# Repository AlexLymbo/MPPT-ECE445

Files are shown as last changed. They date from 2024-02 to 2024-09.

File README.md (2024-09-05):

# Senior Design Project(ECE445) - Custom Illini Solar Car MPPT
This project contains both the HW and FW for a boost converter MPPT made for the 3rd generation vehicle of Illini Solar Car. It utilizes a simple perturb and observe algorithm (P&O).

## More Info: 
The goal of this project was to develop custom and low cost solar Maximum Power Point Trackers (MPPTs). These MPPTs use a boost converter to optimize power output from the solar array to charge the battery efficiently. With the array divided into three sections for reliability, each MPPT gives redundancy to the system. Customization gives simple integration with the vehicle's electrical systems, allowing for plug-and-play functionality. This cost-effective solution takes away the need for expensive off-the-shelf components and provides access to schematics for easy maintenance and upgrades. 

https://www.youtube.com/watch?v=uG63rXX1FN4&t=2s

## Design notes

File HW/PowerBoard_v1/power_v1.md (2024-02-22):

# Wheel v8.1
**Board Requirements**

## Overview and Description
- This board is the steering wheel on the car including most of the I/O from/to the driver. 
- This replaces Wheel v7 as it is a new mechanical design and adds more input functionality.
- Most of the functionality will be combined into one PCB:
	- The wheel bridge board has the major power protection circuitry on it.
- Other board integration
	- Dash (CAN)
	- MCC (CAN)
	- BMS (CAN)
	- PDS (CAN)
	- PTT Radio (Hard wire)
- Wiki page: [Wheel v8](https://wiki.illinisolarcar.com/w/index.php/Wheel_v8)

## High-Level Requirements
- Microcontroller
	- [LPC1549](https://www.nxp.com/docs/en/data-sheet/LPC15XX.pdf)
	- Integrated CAN
	- JTAG Programming
	- Reset buttons
- Driver Controls
	- Turn Signals
		- A three position switch for right, left, and no turn options
	- Push To Talk
		- Comply with ASC/WSC hands free rules
		- Work independently of car
	- Horn
	- Accelerator
		- Analog input, at least 120 values within movement range of encoder
	- Regen
		- Analog input, at least 120 values within movement range of encoder
	- Cruise mode enable
	- Coast button
	- Reset
	- OK/Flag Button
		- To allow driver to flag abnormalities and menu interaction
	- Directional button
		- For menu interaction
- Informational Displays
	- OLED 
		- Powered and controlled by the steering wheel, also mounted to steering wheel
		- Provides real-time telemetry data to driver from all CANBUS-connected PCBs
		- Driver can customize what telemetry is visible on the screen
		- Driver must control from steering wheel
	- 7 Segment Displays
		- Display speed independent of what the driver is doing on the menu
- LED Indicators
	- Indicate status of turn signal/hazard lights, parking lights, and head lights / DRLs
		- Must comply with pilot light size requirements
- External Connections
	- Can only use 12, all via quick disconnect hub
- Mechanical Design
	- Except for the display, everything should be on one PCB or panel mounted to the wheel itself. 
	- All components will be on one side except those with cutouts to the front and items ?mm(unknown at this point) in height in other areas
	- Care must be taken not to interfere with usage of the disconnect hub	

## Communication Protocols
- CAN Bus
	- Used to receive all needed data and send driver commands
	- Termination will be available on the steering wheel
	- CAN Planes will be isolated from main wheel power planes
- SPI
	- Used with encoder, 7-seg, and OLED

## Connectors
- 12 Pin Quick Disconnect hub
    - 5 Wire CAN
	- 1 Wire +24V Critical
	- 1 Wire GND Critical
	- 1 Wire Connection Sense
	- 2 PTT Wires
	- 2 Free (any cool ideas?)
- Low profile connectors should be used to prevent the anything from getting knocked loose in normal use
- Using microclasp connectors

## ICs
- X,Y axis accelerometer to detect wheel turning

## Buttons/Switches
- Buttons are described in high level requirements
- Non-SMD or THT buttons will have connectors next to them
- All buttons will go to GPIO pins
- Buttons should be panel mount
- Menu button should be a 1-axis toggle

## Power System
- +24V
	- Input power from LV Bus
	- Must be 24V through wheel connector due to wire ratings/limits
	- Power protection will occur on the wheel bridge
- +3.3V
	- DC-DC converter on the wheel will provide 24V -> 3.3V
	     - Alternatively 3.3V may be powered via USB for re-programming
	- Used to power everything on the board and all peripherals
- USB Power
    - +5V via micro-usb, regulated to 3.3V as secondary 3.3V supply
- CAN Power
    - Input from 5-Wire CAN Connections
	- Fused On Board
	- Should be ~+12V
- +5V CAN
    - Regulated from CAN Power
	- Power Isolated CAN Side of CAN Transciever

## Test Points
- +24V
- +SuperCap Power
- +3.3V
- I2C SCL & SDA
- SPI CLK/MOSI/MISO1/MISO2/Chip Selects
- Connection Sense
- SuperCap Power Sense
- GND where needed as Reference
- CAN +/- & H/L

## LED Indicators
- Onboard LEDs:
	- Heartbeat
	- CAN Receive
	- CAN Send
	- Displays functionality
	- CAN Termination

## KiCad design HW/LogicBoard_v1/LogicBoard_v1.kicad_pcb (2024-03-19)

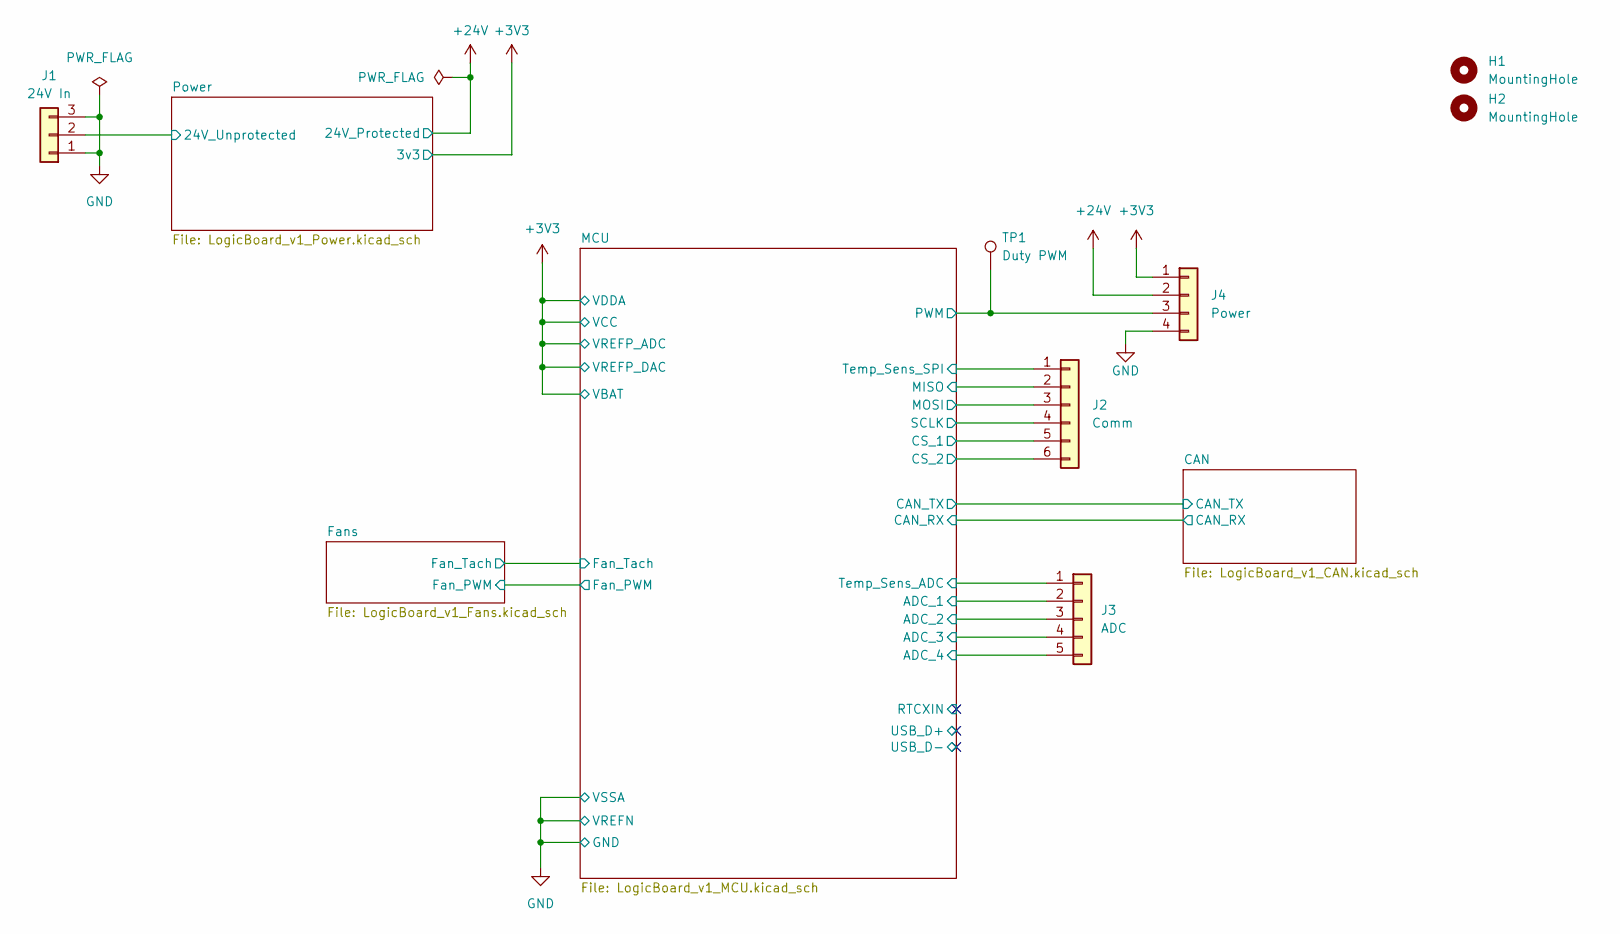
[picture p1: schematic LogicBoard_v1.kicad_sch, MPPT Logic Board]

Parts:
H1, H2: MountingHole; MountingHole_3.2mm_M3
J1: 24V In; Molex_Micro-Fit_3.0_43650-0300_1x03_P3.00mm_Horizontal; MPN 436500300
J2: Comm; Molex_Micro-Fit_3.0_43650-0600_1x06_P3.00mm_Horizontal; MPN 436500600
J3: ADC; Molex_Micro-Fit_3.0_43650-0500_1x05_P3.00mm_Horizontal; MPN 436500500
J4: Power; Molex_Micro-Fit_3.0_43650-0400_1x04_P3.00mm_Horizontal; MPN 436500400
TP1: Duty PWM; TestPoint_THTPad_D1.5mm_Drill0.7mm

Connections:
+3V3: J4.1; also elsewhere on the board
+24V: J4.2; also elsewhere on the board
/MCU/ADC_1: J3.2; also elsewhere on the board
/MCU/ADC_2: J3.3; also elsewhere on the board
/MCU/ADC_3: J3.4; also elsewhere on the board
/MCU/ADC_4: J3.5; also elsewhere on the board
/MCU/CS_1: J2.5; also elsewhere on the board
/MCU/CS_2: J2.6; also elsewhere on the board
/MCU/MISO: J2.2; also elsewhere on the board
/MCU/MOSI: J2.3; also elsewhere on the board
/MCU/PWM: J4.3, TP1.1; also elsewhere on the board
/MCU/SCLK: J2.4; also elsewhere on the board
/MCU/Temp_Sens_ADC: J2.1, J3.1; also elsewhere on the board
/Power/24V_Unprotected: J1.2; also elsewhere on the board
GND: J1.1, J1.3, J4.4; also elsewhere on the board

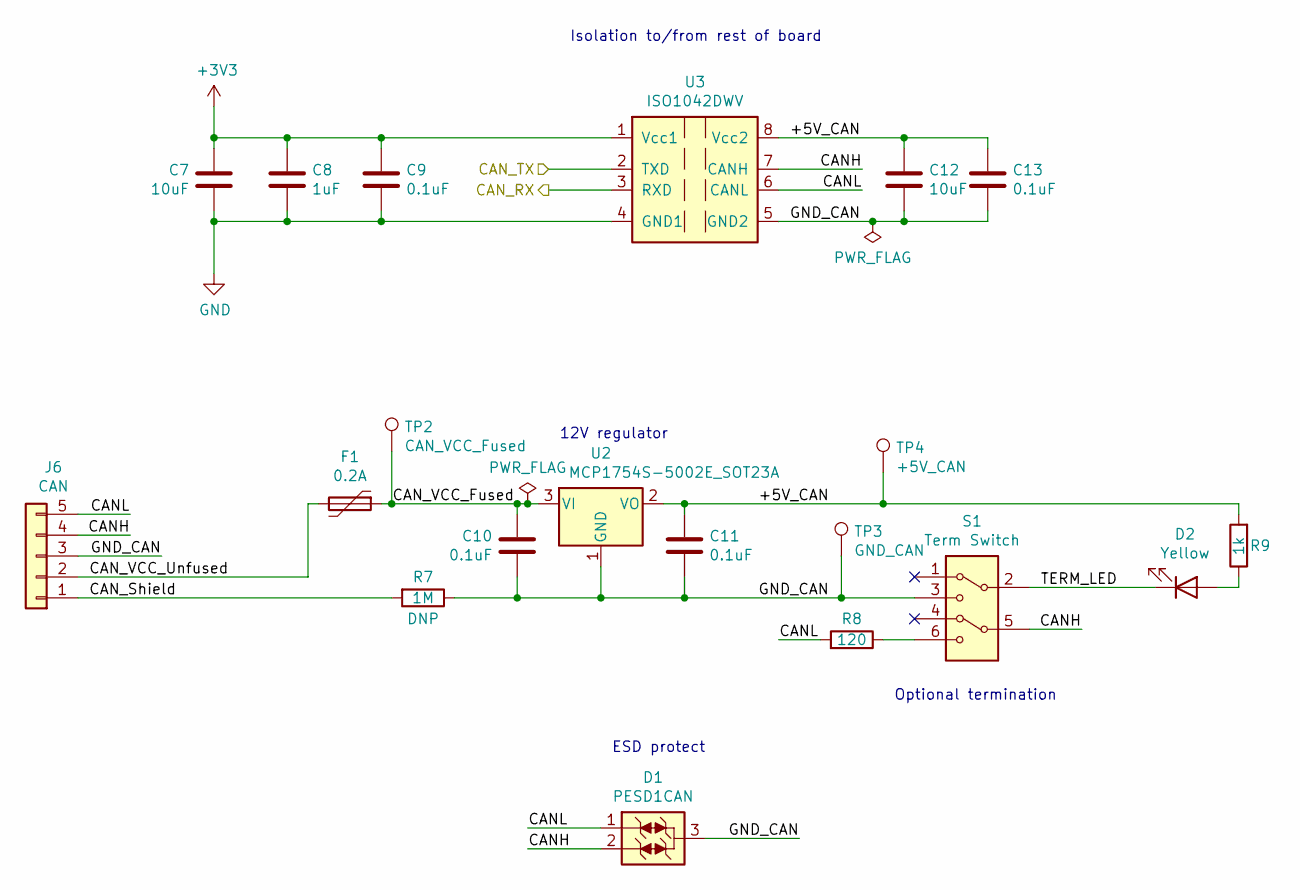
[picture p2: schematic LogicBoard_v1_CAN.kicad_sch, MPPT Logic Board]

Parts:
C7: 10uF; C_1206_3216Metric_Pad1.33x1.80mm_HandSolder; MPN CAP CER 10UF 10V X5R 1206
C8: 1uF; C_0805_2012Metric_Pad1.18x1.45mm_HandSolder; MPN CAP CER 1UF 10V X5R 0805
C9, C11: 0.1uF; C_0603_1608Metric_Pad1.08x0.95mm_HandSolder; MPN CAP CER 0.1UF 10V X5R 0603
C10: 0.1uF; C_0603_1608Metric_Pad1.08x0.95mm_HandSolder; MPN CAP CER 0.1UF 16V X5R 0603
C12: 10uF; C_1206_3216Metric_Pad1.33x1.80mm_HandSolder; MPN CAP CER 10UF 25V X5R 1206
C13: 0.1uF; C_0603_1608Metric_Pad1.08x0.95mm_HandSolder; MPN CAP CER 0.1UF 25V X5R 0603
D1: PESD1CAN; SOT-23; MPN PESD1CAN,215
D2: Yellow; LED_0603_1608Metric_Pad1.05x0.95mm_HandSolder; MPN LED YELLOW CLEAR 0603 SMD
F1: 0.2A; Fuse_1206_3216Metric_Pad1.42x1.75mm_HandSolder; MPN PTC RESET FUSE 30V 200MA 1206
J6: CAN; M12_5-pin_90deg_VertPitch2.54mm; MPN 1694224
R7: 1M; R_0603_1608Metric_Pad0.98x0.95mm_HandSolder; MPN RES SMD 1M OHM 1% 1/10W 0603
R8: 120; R_1206_3216Metric_Pad1.30x1.75mm_HandSolder; MPN RES SMD 120 OHM 1% 1/4W 1206
R9: 1k; R_0603_1608Metric_Pad0.98x0.95mm_HandSolder; MPN RES SMD 1K OHM 5% 1/10W 0603
S1: CL-SB-22B-01; DPDT_NIDEC_6_pin_SMD_1.6_x_1.2_pads; MPN CL-SB-22B-01
TP2: CAN_VCC_Fused; TestPoint_THTPad_D1.5mm_Drill0.7mm
TP3: GND_CAN; TestPoint_THTPad_D1.5mm_Drill0.7mm
TP4: +5V_CAN; TestPoint_THTPad_D1.5mm_Drill0.7mm
U2: MCP1754S-5002E_SOT23A; SOT-23; MPN MCP1754S-5002E_SOT23A
U3: ISO1042DWV; SOIC-8_5.85x7.4mm_P1.27mm; MPN ISO1042DWV

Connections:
+3V3: C7.1, C8.1, C9.1, U3.1 (Vcc1); also elsewhere on the board
/CAN/+5V_CAN: C11.1, C12.1, C13.1, R9.2, TP4.1, U2.2 (VO), U3.8 (Vcc2)
/CAN/CANH: D1.2 (K), J6.4, S1.5, U3.7 (CANH)
/CAN/CANL: D1.1 (K), J6.5, R8.2, U3.6 (CANL)
/CAN/CAN_RX: U3.3 (RXD); also elsewhere on the board
/CAN/CAN_Shield: J6.1, R7.2
/CAN/CAN_TX: U3.2 (TXD); also elsewhere on the board
/CAN/CAN_VCC_Fused: C10.1, F1.1, TP2.1, U2.3 (VI)
/CAN/CAN_VCC_Unfused: F1.2, J6.2
/CAN/GND_CAN: C10.2, C11.2, C12.2, C13.2, D1.3 (A), J6.3, R7.1, S1.3, TP3.1, U2.1 (GND), U3.5 (GND2)
/CAN/TERM_LED: D2.1 (K), S1.2
GND: C7.2, C8.2, C9.2, U3.4 (GND1); also elsewhere on the board
unnamed: D2.2 (A), R9.1
unnamed: R8.1, S1.6

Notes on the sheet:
ESD protect
12V regulator
Optional termination
Isolation to/from rest of board

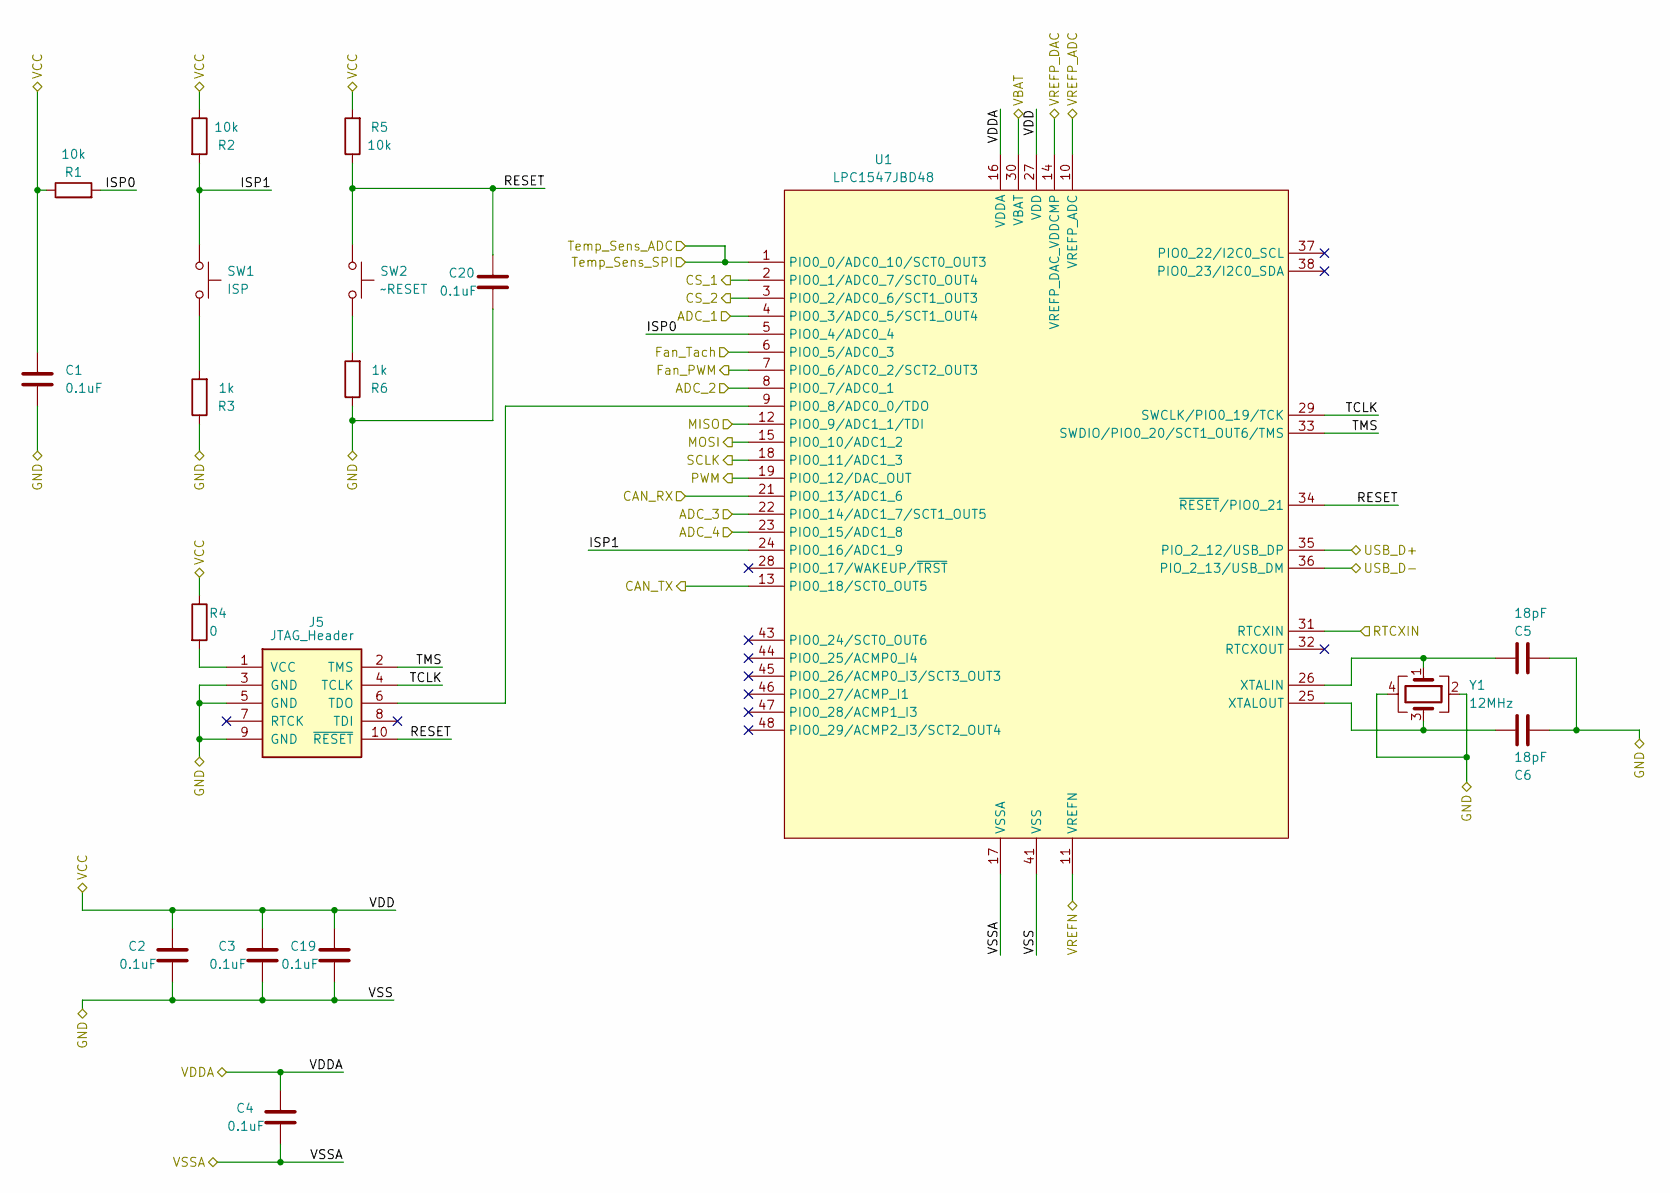
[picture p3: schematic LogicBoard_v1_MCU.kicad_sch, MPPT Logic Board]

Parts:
C1, C2, C3, C4, C19, C20: 0.1uF; C_0603_1608Metric_Pad1.08x0.95mm_HandSolder; MPN CAP CER 0.1uF 10V X7R 0603
C5, C6: 18pF; C_0603_1608Metric_Pad1.08x0.95mm_HandSolder; MPN CAP CER 18pF 10V X7R 0603
J5: JTAG_Header; IDC-Header_2x05_Pitch1.27mm_Straight; MPN 3220-10-0100-00
R1, R2, R5: 10k; R_0603_1608Metric_Pad0.98x0.95mm_HandSolder; MPN RES SMD 10K OHM 1% 1/4W 0603
R3, R6: 1k; R_0603_1608Metric_Pad0.98x0.95mm_HandSolder; MPN RES SMD 1K OHM 5% 1/4W 0603
R4: 0; R_0603_1608Metric_Pad0.98x0.95mm_HandSolder; MPN RES SMD 0 OHM 5% 1/4W 0603
SW1: ISP; Button_223AM; MPN 223AMVAAR
SW2: ~RESET; Button_223AM; MPN 223AMVAAR
U1: LPC1547JBD48; LQFP-48_7x7mm_P0.5mm; MPN LPC1547JBD48
Y1: 12MHz; Crystal_SMD_TXC_7M-4pin_3.2x2.5mm; MPN 7V-12.000MAAE-T

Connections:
+3V3: C1.1, C2.1, C3.1, C4.1, C19.1, R1.1, R2.1, R4.1, R5.2, U1.10 (VREFP_ADC), U1.14 (VREFP_DAC_VDDCMP), U1.16 (VDDA), U1.27 (VDD), U1.30 (VBAT), U1.39 (VDD), U1.42 (VDD); also elsewhere on the board
/CAN/CAN_RX: U1.21 (PIO0_13/ADC1_6); also elsewhere on the board
/CAN/CAN_TX: U1.13 (PIO0_18/SCT0_OUT5); also elsewhere on the board
/Fans/Fan_PWM: U1.7 (PIO0_6/ADC0_2/SCT2_OUT3); also elsewhere on the board
/Fans/Fan_Tach: U1.6 (PIO0_5/ADC0_3); also elsewhere on the board
/MCU/ADC_1: U1.4 (PIO0_3/ADC0_5/SCT1_OUT4); also elsewhere on the board
/MCU/ADC_2: U1.8 (PIO0_7/ADC0_1); also elsewhere on the board
/MCU/ADC_3: U1.22 (PIO0_14/ADC1_7/SCT1_OUT5); also elsewhere on the board
/MCU/ADC_4: U1.23 (PIO0_15/ADC1_8); also elsewhere on the board
/MCU/CS_1: U1.2 (PIO0_1/ADC0_7/SCT0_OUT4); also elsewhere on the board
/MCU/CS_2: U1.3 (PIO0_2/ADC0_6/SCT1_OUT3); also elsewhere on the board
/MCU/ISP0: R1.2, U1.5 (PIO0_4/ADC0_4)
/MCU/ISP1: R2.2, SW1.1, U1.24 (PIO0_16/ADC1_9)
/MCU/MISO: U1.12 (PIO0_9/ADC1_1/TDI); also elsewhere on the board
/MCU/MOSI: U1.15 (PIO0_10/ADC1_2); also elsewhere on the board
/MCU/PWM: U1.19 (PIO0_12/DAC_OUT); also elsewhere on the board
/MCU/RESET: C20.1, J5.10 (~RESET), R5.1, SW2.1, U1.34 (~RESET/PIO0_21)
/MCU/RTCXIN: U1.31 (RTCXIN)
/MCU/SCLK: U1.18 (PIO0_11/ADC1_3); also elsewhere on the board
/MCU/TCLK: J5.4 (TCLK), U1.29 (SWCLK/PIO0_19/TCK)
/MCU/TMS: J5.2 (TMS), U1.33 (SWDIO/PIO0_20/SCT1_OUT6/TMS)
/MCU/Temp_Sens_ADC: U1.1 (PIO0_0/ADC0_10/SCT0_OUT3); also elsewhere on the board
/MCU/USB_D+: U1.35 (PIO_2_12/USB_DP)
/MCU/USB_D-: U1.36 (PIO_2_13/USB_DM)
GND: C1.2, C2.2, C3.2, C4.2, C5.1, C6.1, C19.2, C20.2, J5.3 (GND), J5.5 (GND), J5.9 (GND), R3.1, R6.1, U1.11 (VREFN), U1.17 (VSSA), U1.20 (VSS), U1.40 (VSS), U1.41 (VSS), Y1.2, Y1.4; also elsewhere on the board
unnamed: J5.6 (TDO), U1.9 (PIO0_8/ADC0_0/TDO)
unnamed: J5.1 (VCC), R4.2
unnamed: R3.2, SW1.2
unnamed: R6.2, SW2.2
unnamed: C5.2, U1.26 (XTALIN), Y1.1
unnamed: C6.2, U1.25 (XTALOUT), Y1.3

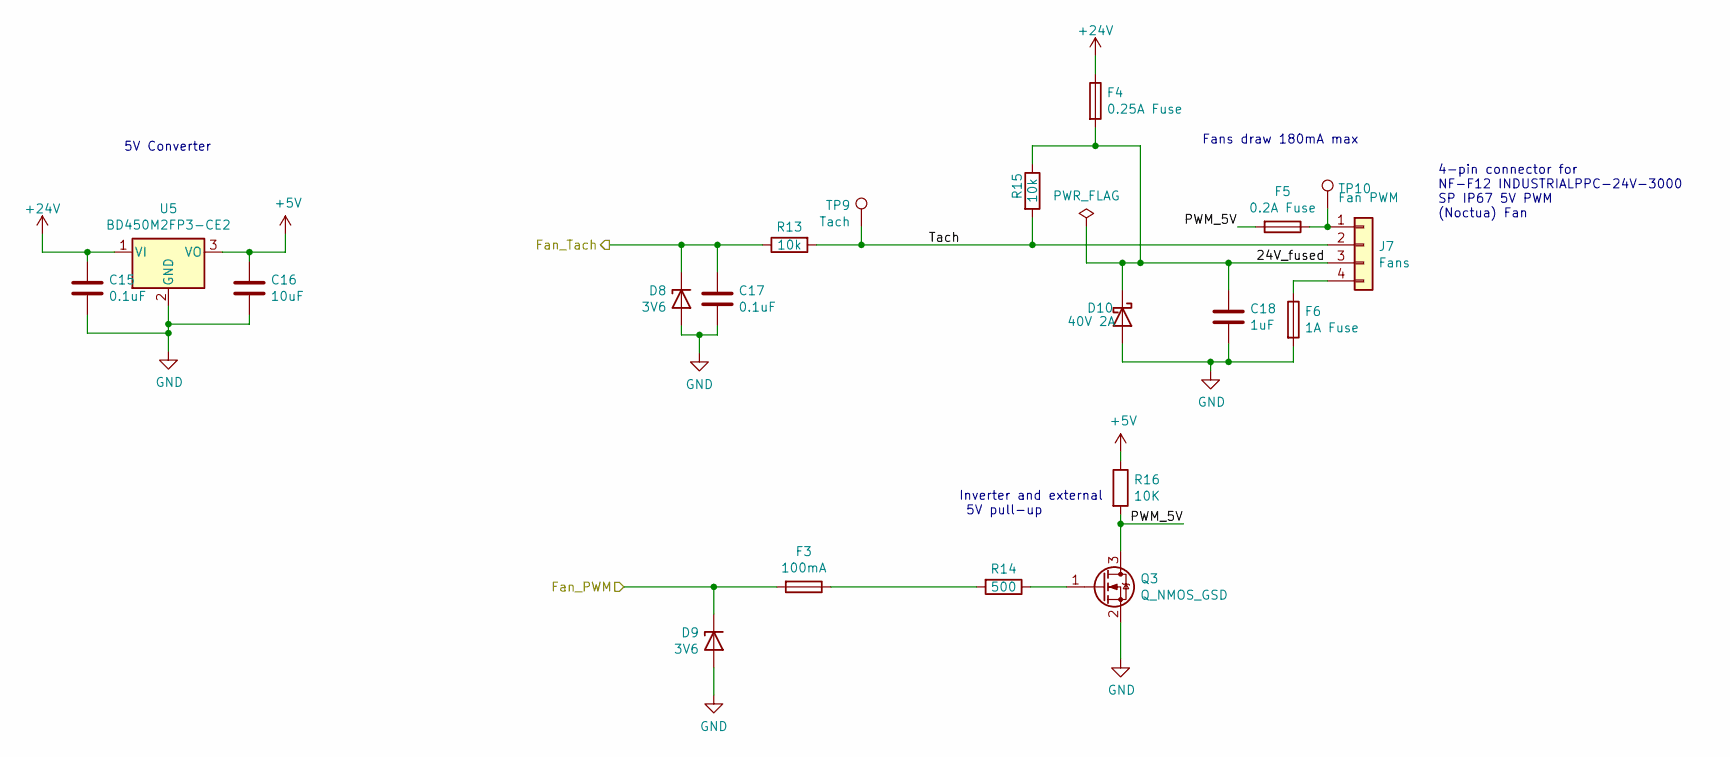
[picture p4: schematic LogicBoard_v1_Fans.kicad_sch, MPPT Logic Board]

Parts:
C15: 0.1uF; C_0603_1608Metric_Pad1.08x0.95mm_HandSolder; MPN CAP CER 0.1uF 50V X5R 0603
C16: 10uF; C_0603_1608Metric_Pad1.08x0.95mm_HandSolder; MPN CAP CER 10uF 10V X5R 0603
C17: 0.1uF; C_0603_1608Metric_Pad1.08x0.95mm_HandSolder; MPN CAP CER 0.1UF 10V X5R 0603
C18: 1uF; C_0603_1608Metric_Pad1.08x0.95mm_HandSolder; MPN CAP CER 1UF 50V X5R 0603
D8, D9: 3V6; D_SOD-123F; MPN NZH3V6B
D10: 40V 2A; D_1206_3216Metric_Pad1.42x1.75mm_HandSolder; MPN SD1206T040S2R0
F3: 100mA; Fuse_2512_6332Metric; MPN 0451.100MRL
F4: 0.25A Fuse; Fuse_1206_3216Metric_Pad1.42x1.75mm_HandSolder; MPN FUSE BOARD MNT 0.25A 32VDC 1206
F5: 0.2A Fuse; Fuse_1206_3216Metric_Pad1.42x1.75mm_HandSolder; MPN FUSE BOARD MNT 0.2A 32VDC 1206
F6: 1A Fuse; Fuse_1206_3216Metric_Pad1.42x1.75mm_HandSolder; MPN FUSE BOARD MNT 1A 32VDC 1206
J7: Fans; Molex_KK-254_AE-6410-04A_1x04_P2.54mm_Vertical
Q3: Q_NMOS_GSD; SOT-23_Handsoldering; MPN BSS123L
R13, R15: 10k; R_0603_1608Metric_Pad0.98x0.95mm_HandSolder; MPN RES SMD 10K OHM 5% 1/10W 0603
R14: 500; R_0603_1608Metric_Pad0.98x0.95mm_HandSolder; MPN RES SMD 500 OHM 5% 1/10W 0603
R16: 10K; R_0603_1608Metric_Pad0.98x0.95mm_HandSolder; MPN RES SMD 10k OHM 5% 1/10W 0603
TP9: Tach; TestPoint_THTPad_D1.5mm_Drill0.7mm
TP10: Fan PWM; TestPoint_THTPad_D1.5mm_Drill0.7mm
U5: BD450M2FP3-CE2; SOT-223-3_TabPin2; MPN BD450M2FP3-CE2

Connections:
+5V: C16.1, R16.1, U5.3 (VO)
+24V: C15.1, F4.1, U5.1 (VI); also elsewhere on the board
/Fans/24V_fused: C18.1, D10.1 (K), F4.2, J7.3, R15.1
/Fans/Fan_PWM: D9.1 (K), F3.2; also elsewhere on the board
/Fans/Fan_Tach: C17.2, D8.1 (K), R13.1; also elsewhere on the board
/Fans/PWM_5V: F5.2, Q3.3 (D), R16.2
/Fans/Tach: J7.2, R13.2, R15.2, TP9.1
GND: C15.2, C16.2, C17.1, C18.2, D8.2 (A), D9.2 (A), D10.2 (A), F6.2, Q3.2 (S), U5.2 (GND); also elsewhere on the board
unnamed: F3.1, R14.2
unnamed: F5.1, J7.1, TP10.1
unnamed: F6.1, J7.4
unnamed: Q3.1 (G), R14.1

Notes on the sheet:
5V Converter
4-pin connector for NF-F12 INDUSTRIALPPC-24V-3000 SP IP67 5V PWM (Noctua) Fan
Inverter and external 5V pull-up
Fans draw 180mA max

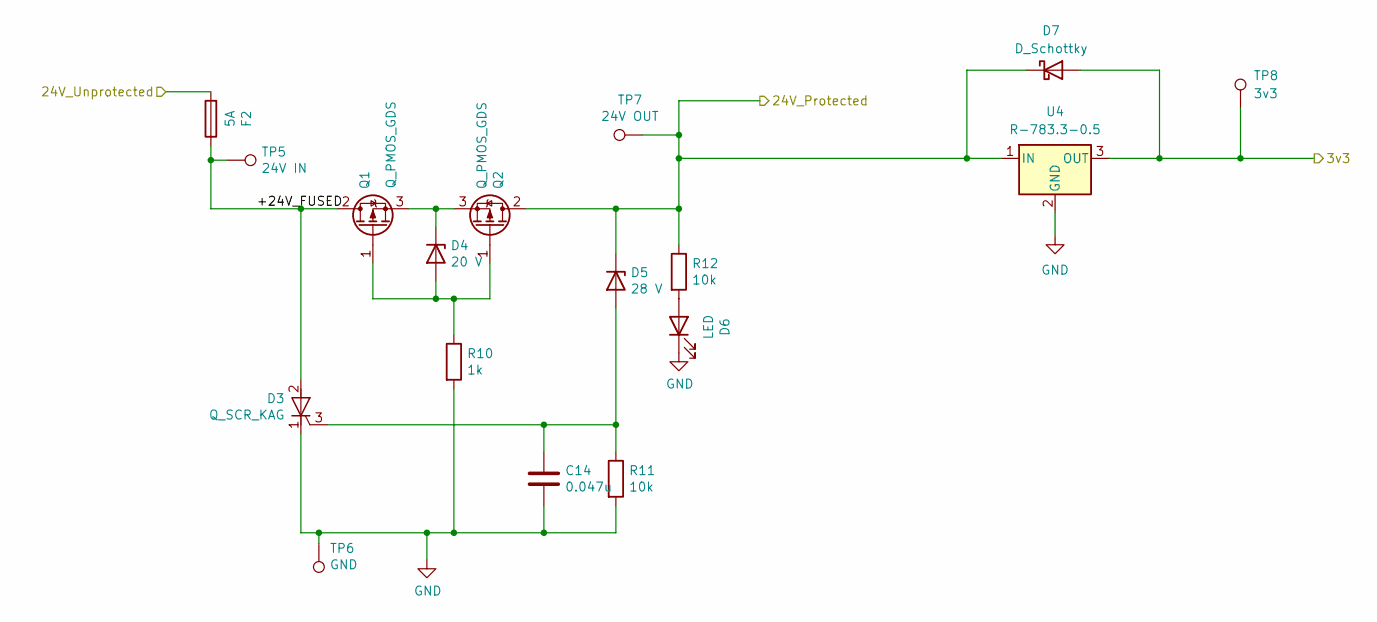
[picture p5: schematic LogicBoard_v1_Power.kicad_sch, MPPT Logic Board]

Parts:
C14: 0.047u; C_0603_1608Metric_Pad1.08x0.95mm_HandSolder; MPN CAP CER 0.047UF 50V X7R 0603
D3: Q_SCR_KAG; SOT-223-3_TabPin2; MPN S602TSRP
D4: 20 V; D_SOD-123F; MPN DIODE ZENER 20V 500MW SOD123F
D5: 28 V; D_SOD-123F; MPN DIODE ZENER 28V 500mW SOD123F
D6: LED; LED_0603_1608Metric_Pad1.05x0.95mm_HandSolder; MPN LED BLUE CLEAR 0603 SMD
D7: D_Schottky; D_SOD-123F; MPN BAT54H
F2: 5A; Littelfuse_154_4.24mm_x_3.81mm; MPN FUSE BOARD MNT 5A 125VAC/VDC SMD
Q1, Q2: Q_PMOS_GDS; TO-252-2; MPN FQD11P06
R10: 1k; R_0603_1608Metric_Pad0.98x0.95mm_HandSolder; MPN RES SMD 1K OHM 5% 0.1W 0603
R11, R12: 10k; R_0603_1608Metric_Pad0.98x0.95mm_HandSolder; MPN RES SMD 10K OHM 5% 0.1W 0603
TP5: 24V IN; TestPoint_THTPad_D1.5mm_Drill0.7mm
TP6: GND; TestPoint_THTPad_D1.5mm_Drill0.7mm
TP7: 24V OUT; TestPoint_THTPad_D1.5mm_Drill0.7mm
TP8: 3v3; TestPoint_THTPad_D1.5mm_Drill0.7mm
U4: R-783.3-0.5; Converter_DCDC_RECOM_R-78E-0.5_THT; MPN R-783.3-0.5

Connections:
+3V3: D7.2 (A), TP8.1, U4.3 (OUT); also elsewhere on the board
+24V: D5.1 (K), D7.1 (K), Q2.2 (D), R12.1, TP7.1, U4.1 (IN); also elsewhere on the board
/Power/24V_Unprotected: F2.2; also elsewhere on the board
/Power/+24V_FUSED: D3.2 (A), F2.1, Q1.2 (D), TP5.1
GND: C14.2, D3.1 (K), D6.1 (K), R10.2, R11.2, TP6.1, U4.2 (GND); also elsewhere on the board
unnamed: C14.1, D3.3 (G), D5.2 (A), R11.1
unnamed: D4.2 (A), Q1.1 (G), Q2.1 (G), R10.1
unnamed: D4.1 (K), Q1.3 (S), Q2.3 (S)
unnamed: D6.2 (A), R12.2

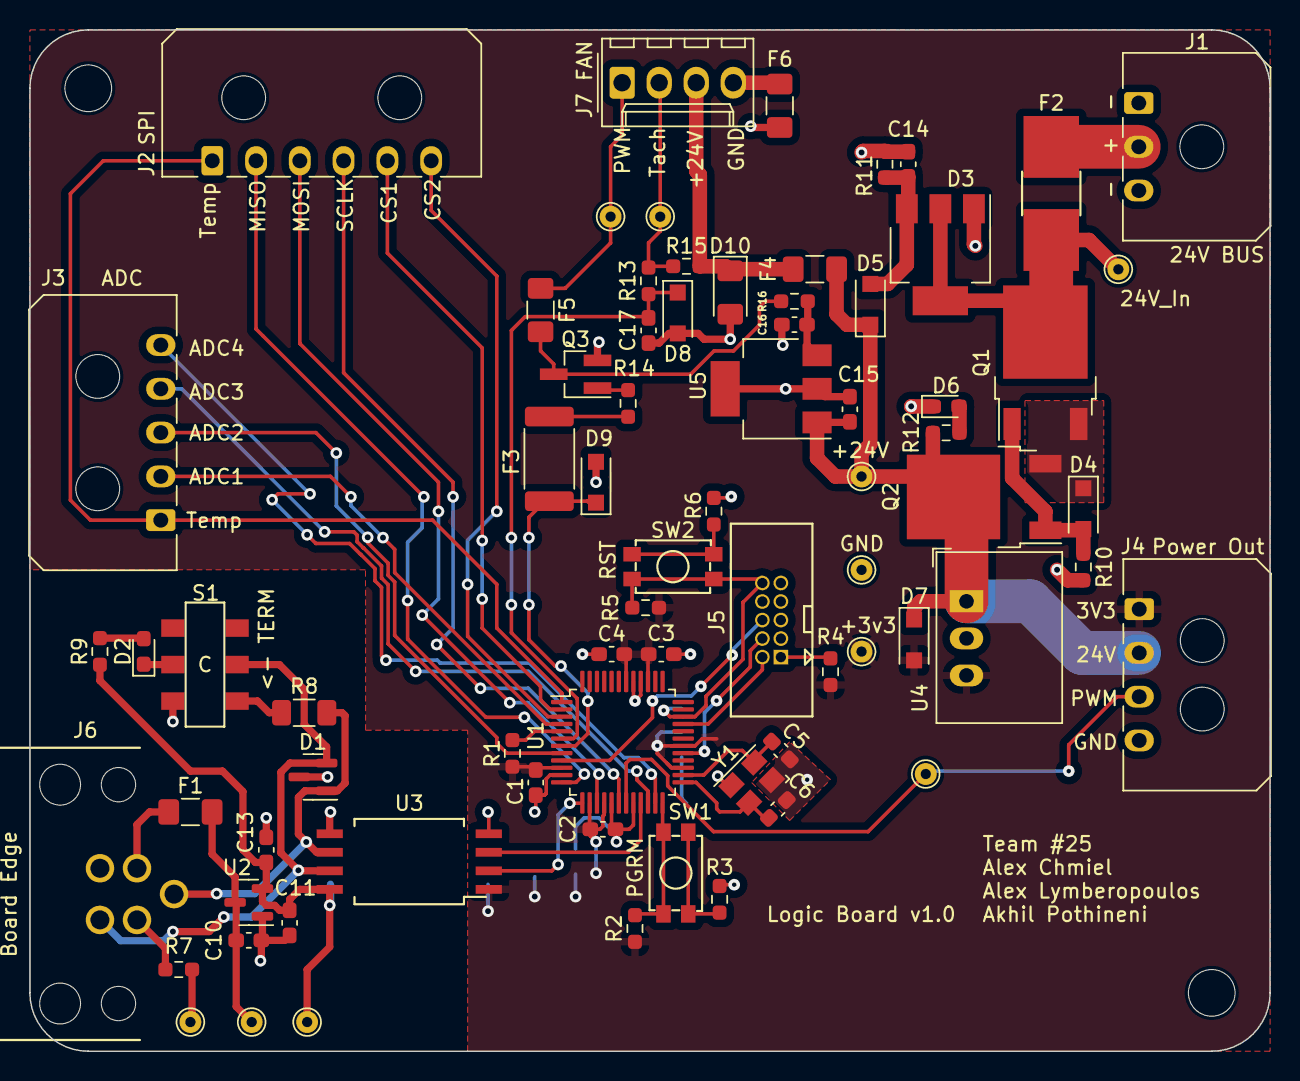
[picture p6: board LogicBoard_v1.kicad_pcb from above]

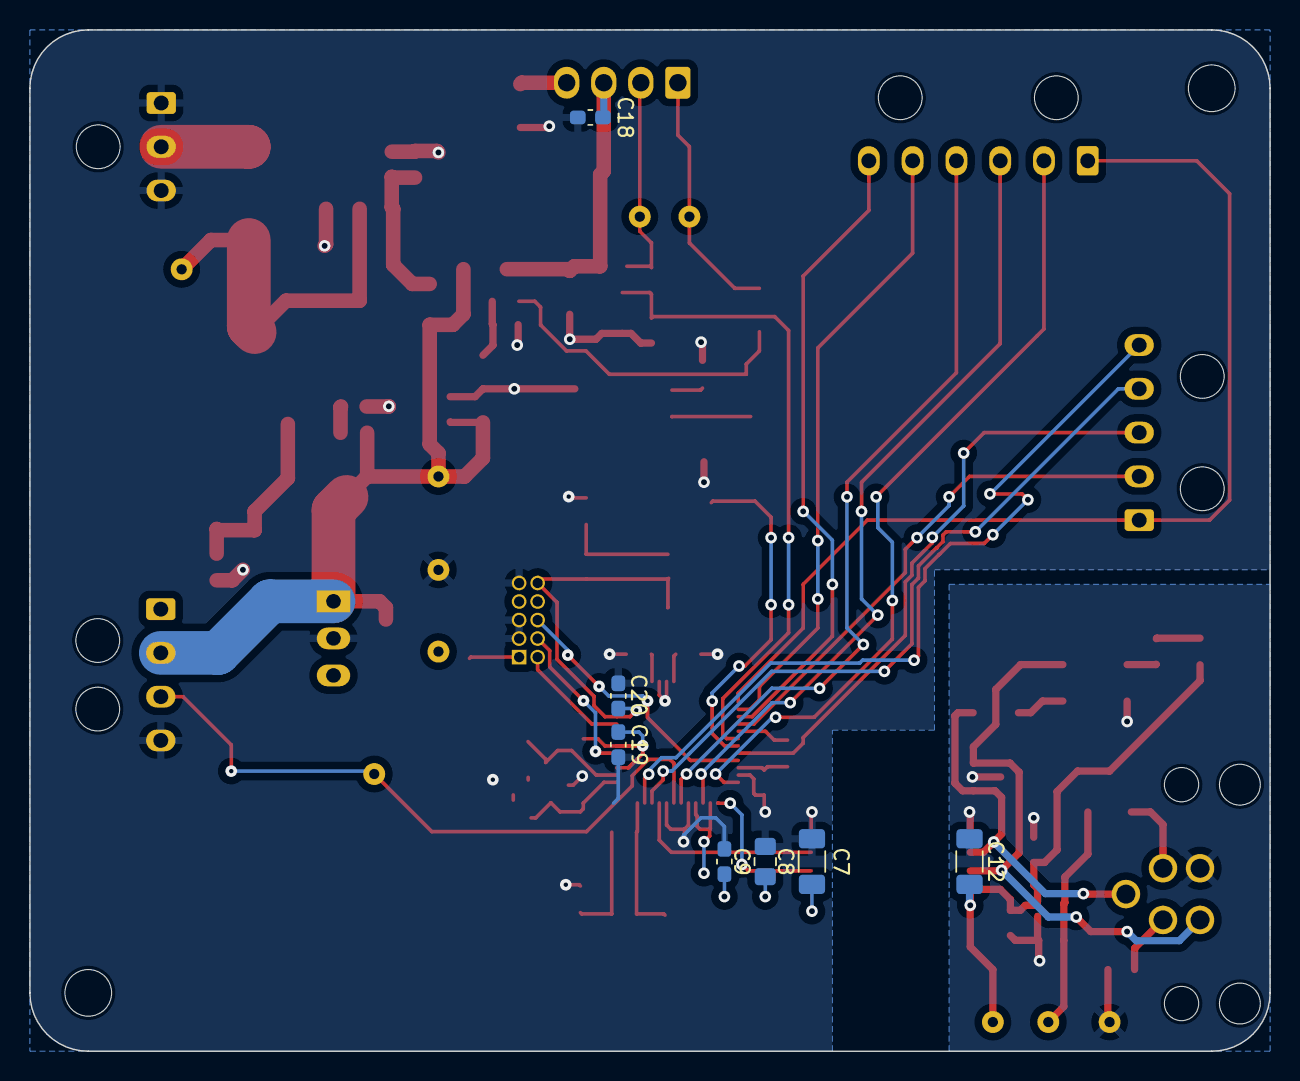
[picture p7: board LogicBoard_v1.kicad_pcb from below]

Board: 2 copper layers, 85.0 x 70.0 mm, 83 parts (7 on the bottom side), 53 nets.

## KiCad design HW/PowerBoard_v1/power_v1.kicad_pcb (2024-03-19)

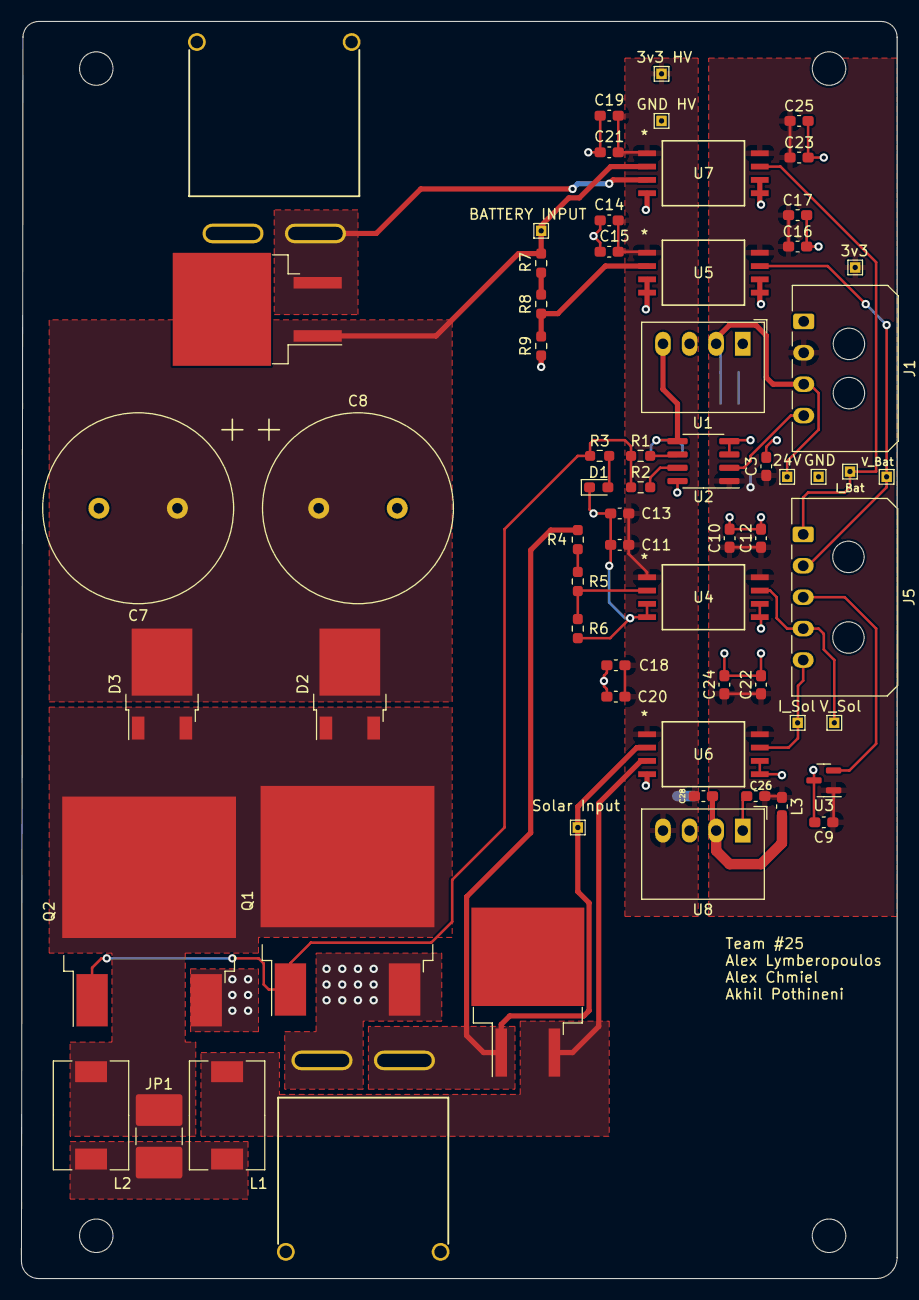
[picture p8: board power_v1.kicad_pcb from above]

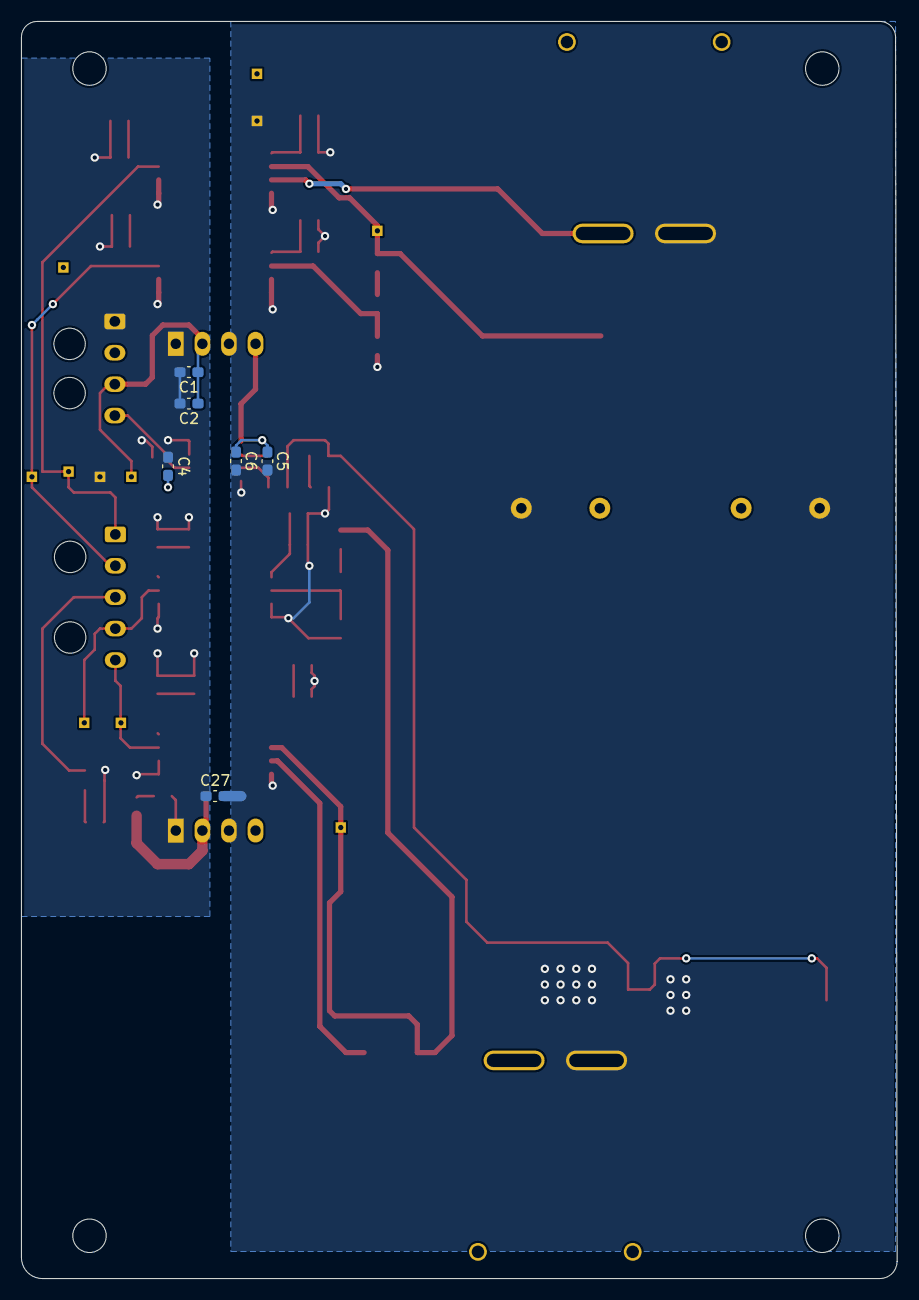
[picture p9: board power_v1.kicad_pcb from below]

Board: 2 copper layers, 83.6 x 120.1 mm, 75 parts (6 on the bottom side), 27 nets.

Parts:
C1, C26: 10uF; C_0603_1608Metric_Pad1.08x0.95mm_HandSolder
C2, C28: 1nF; C_0603_1608Metric_Pad1.08x0.95mm_HandSolder
C3, C4, C5, C6, C12, C13, C14, C17, C18, C19, C24, C25: 1uF; C_0603_1608Metric_Pad1.08x0.95mm_HandSolder
C7, C8: 470uF; C_Radial_D18.0mm_H35.5mm_P7.50mm
C9: 0.1uF; C_0603_1608Metric_Pad1.08x0.95mm_HandSolder
C10, C11, C15, C16, C20, C21, C22, C23: 100nF; C_0603_1608Metric_Pad1.08x0.95mm_HandSolder
C27: 2.2nF; C_0603_1608Metric_Pad1.08x0.95mm_HandSolder
D1: Blue; LED_0603_1608Metric_Pad1.05x0.95mm_HandSolder
D2, D3: 0.83V; TO-252-2
H1, H2, H3, H4: MountingHole; MountingHole_3.2mm_M3
J1: Inputs; Molex_Micro-Fit_3.0_43650-0400_1x04_P3.00mm_Horizontal
J3: Vin Solar; Anderson_Powerpole_45A_1x2_Horizontal_Bottom
J4: Vout Battery; Anderson_Powerpole_45A_1x2_Horizontal_Bottom
J5: Sensors; Molex_Micro-Fit_3.0_43650-0500_1x05_P3.00mm_Horizontal
JP1: SolderJumper_2_Open; R_2816_7142Metric
L1, L2: 1.2 μH; L_Wuerth_HCM-1050
L3: 22uH; L_0603_1608Metric_Pad1.05x0.95mm_HandSolder
Q1, Q2: IXTT220N20X4HV; TO-268-2
R1: 10; R_0603_1608Metric_Pad0.98x0.95mm_HandSolder
R2: 0; R_0603_1608Metric_Pad0.98x0.95mm_HandSolder
R3: 10k; R_0603_1608Metric_Pad0.98x0.95mm_HandSolder
R4, R5, R7, R8: 500k; R_0603_1608Metric_Pad0.98x0.95mm_HandSolder
R6: 53k; R_0603_1608Metric_Pad0.98x0.95mm_HandSolder
R9: 41.7k; R_0603_1608Metric_Pad0.98x0.95mm_HandSolder
R10, R11: 0.75; TO-263-2_isolatedback
TP1: +3V3A; TestPoint_THTPad_1.0x1.0mm_Drill0.5mm
TP2: GNDA; TestPoint_THTPad_1.0x1.0mm_Drill0.5mm
TP3: 24V; TestPoint_THTPad_1.0x1.0mm_Drill0.5mm
TP4: GND; TestPoint_THTPad_1.0x1.0mm_Drill0.5mm
TP5: 3V3; TestPoint_THTPad_1.0x1.0mm_Drill0.5mm
TP6: ADC V Sol; TestPoint_THTPad_1.0x1.0mm_Drill0.5mm
TP7, TP11: ADC V Batt; TestPoint_THTPad_1.0x1.0mm_Drill0.5mm
TP8: ADC I Sol; TestPoint_THTPad_1.0x1.0mm_Drill0.5mm
TP9, TP13: ADC I Batt; TestPoint_THTPad_1.0x1.0mm_Drill0.5mm
U1: RO-2412S; Converter_DCDC_RECOM_R-78S-0.1_THT
U2: STGAP2SMTR; SOIC-8_3.9x4.9mm_P1.27mm
U3: MCP9700AT-ETT; SOT-23
U4, U5, U6, U7: PAMC1350DWVR; U_PAMC1350DWVR_TEX
U8: 3v3 ISO DC/DC; Converter_DCDC_RECOM_R-78S-0.1_THT

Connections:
+3.3VA: C11.1, C13.1, C14.1, C15.1, C18.1, C19.1, C20.1, C21.1, C28.1, TP1.1, U4.1 (VDD1), U5.1 (VDD1), U6.1 (VDD1), U7.1 (VDD1), U8.4 (+VOUT)
+3V3: C3.1, C4.1, C9.1, C10.1, C12.1, C16.1, C17.1, C22.1, C23.1, C24.1, C25.1, C26.1, J1.2, L3.1, TP5.1, U2.1 (VDD), U3.1 (Vdd), U4.8 (VDD2), U5.8 (VDD2), U6.8 (VDD2), U7.8 (VDD2)
+24V: C1.1, C2.1, J1.3, TP3.1, U1.2 (+VIN)
/ADC I Batt: J5.1, TP9.1, U7.7 (OUTP)
/ADC I Sol: J5.5, TP8.1, U6.7 (OUTP)
/ADC V Batt: J5.2, TP7.1, U5.7 (OUTP)
/ADC V Sol: J5.4, TP6.1, U4.7 (OUTP)
/Batt In: C7.1, C8.1, D2.2 (K), D3.2 (K), R7.1, R11.1, TP11.1, U7.2 (INP)
/Batt Out: J4.1, R11.2, U7.3 (INN)
/Board Temp: J5.3, U3.2 (Vout)
/DNP Anode: D2.1 (A), D2.3 (A), D3.1 (A), D3.3 (A), JP1.2 (B), L2.2, Q1.2 (D), Q2.2 (D)
/Gate: Q1.1 (G), Q2.1 (G), R1.1, R2.1, R3.1
/PWM: J1.4, U2.2 (IN+)
/SW_G+: R1.2, U2.6 (GON)
/SW_G-: R2.2, U2.7 (GOFF)
/Sensors/V Sense Batt: R8.2, R9.1, U5.2 (INP)
/Sensors/V Sense Sol: R5.2, R6.1, U4.2 (INP)
/Sol In: J3.2, R4.1, R10.1, TP13.1, U6.2 (INP)
/Sol Out: L1.1, R10.2, U6.3 (INN)
Earth: C5.2, C6.2, C7.2, C8.2, C11.2, C13.2, C14.2, C15.2, C18.2, C19.2, C20.2, C21.2, C27.2, D1.1 (K), J3.1, J4.2, Q1.3 (S), Q2.3 (S), R6.2, R9.2, TP2.1, U1.3 (-VOUT), U2.8 (GNDISO), U4.3 (INN), U4.4 (GND1), U5.3 (INN), U5.4 (GND1), U6.4 (GND1), U7.4 (GND1), U8.3 (-VOUT)
GND: C1.2, C2.2, C3.2, C4.2, C9.2, C10.2, C12.2, C16.2, C17.2, C22.2, C23.2, C24.2, C25.2, C26.2, C27.1, J1.1, TP4.1, U1.1 (-VIN), U2.3 (IN-), U2.4 (GND), U3.3 (GND), U4.5 (GND2), U4.6 (OUTN), U5.5 (GND2), U5.6 (OUTN), U6.5 (GND2), U6.6 (OUTN), U7.5 (GND2), U7.6 (OUTN), U8.1 (-VIN)
unnamed: D1.2 (A), R3.2
unnamed: JP1.1 (A), L1.2, L2.1
unnamed: R4.2, R5.1
unnamed: R7.2, R8.1
unnamed: C5.1, C6.1, U1.4 (+VOUT), U2.5 (VH)
unnamed: C28.2, L3.2, U8.2 (+VIN)

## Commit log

2024-02-22 init hardware stuff
    [power_v1.kicad_pcb, power_v1.kicad_sch]
2024-02-22 boost added to power board
    [Sensors.kicad_sch, power_v1.kicad_sch]
2024-02-22 cleaned up schematic
    [Sensors.kicad_sch, power_v1.kicad_sch]
2024-02-22 update sim to simulate array better
    [Sensors.kicad_sch, power_v1.kicad_sch]
2024-02-23 Started logic board
    [LogicBoard_v1.kicad_pcb, LogicBoard_v1.kicad_sch, LogicBoard_v1_CAN.kicad_sch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]
2024-02-27 Finsihed logic board schematic
    [LogicBoard_v1.kicad_sch, LogicBoard_v1_CAN.kicad_sch, LogicBoard_v1_Fans.kicad_sch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]
2024-03-01 updates sensing
    [Sensors.kicad_sch, power_v1.kicad_sch]
2024-03-04 updated sensing portion
    [Sensors.kicad_sch, power_v1.kicad_sch]
2024-03-05 added resistors for sensing
    [Sensors.kicad_sch, power_v1.kicad_sch]
2024-03-05 small visual changes
    [power_v1.kicad_sch]
2024-03-05 added resistor values for voltage sense
    [Sensors.kicad_sch]
2024-03-05 finished schematic
    [Sensors.kicad_sch]
2024-03-05 error fixing
    [Sensors.kicad_sch, power_v1.kicad_sch]
2024-03-05 updated naming
    [Sensors.kicad_sch, power_v1.kicad_sch]
2024-03-05 name changes
    [Sensors.kicad_sch, power_v1.kicad_sch]
2024-03-05 small layout changes
    [Sensors.kicad_sch, power_v1.kicad_pcb, power_v1.kicad_sch]
2024-03-05 need to figure out current sense res fp
    [power_v1.kicad_pcb]
2024-03-05 more layout
    [Sensors.kicad_sch, power_v1.kicad_pcb]
2024-03-05 more changes
    [Sensors.kicad_sch, power_v1.kicad_pcb, power_v1.kicad_sch]
2024-03-05 added changes
    [power_v1.kicad_pcb]
2024-03-05 pushed board
    [Sensors.kicad_sch, power_v1.kicad_pcb, power_v1.kicad_sch]
2024-03-19 Almost done with logic board
    [LogicBoard_v1.kicad_pcb]
2024-03-19 Finsihed logic board
    [LogicBoard_v1.kicad_pcb, LogicBoard_v1.kicad_sch]
2024-03-21 added ti paper for resistor sizing
    [Sensors.kicad_sch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]
2024-03-28 pushed changes
    [Sensors.kicad_sch]
2024-04-02 added excel
    [ECE445 Data.xlsx]
2024-04-07 Sensor Data
    [ECE445 Data.xlsx]
2024-04-16 updated to add battery voltage measurement
